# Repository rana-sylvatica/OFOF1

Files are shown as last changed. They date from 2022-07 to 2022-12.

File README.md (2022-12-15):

# OFOF1
Open-frame case design for the Open Frame1 board

## Overview

The goal of this project is to create a "bare miniumum" case design for the OF1 board, allowing aspiring makers to construct quality digital controllers as cheaply and simply as possible.

The controller is built as three layers (bottom panel, OF1 board, top panel) separated by standoffs leaving the sides open, hence the "open frame" in the title.  There are two versions of the OFOF1 case, as shown below.  The first one (labeled OFOF1 in the files) uses a top panel with circular cutouts for 3D printed MX switch button housings.  The second version (OFOF1_alt) uses a top panel with square cutouts that fit the MX switches directly.





## OF1 Board

Please refer to the Open Frame1 repository for information about the board

https://github.com/GregTurbo/Open-Frame1

## Panels

There are many ways to fabricate the top and bottom panels.  The method I am using is ordering them as aluminum PCBs from JLCPCB.  This is cheap, strong, and allows for logos or other designs to be built into the panel.  

However, JLCPCB has a minimum order quantity of 5, so this is not the most economical for a one-off build.

Another good method would be to order the panels through a laser-cutting service like SendCutSend (for those in the USA/Canada).  3mm acrylic or MDF or 1.6mm aluminum would both be suitable materials, and wouldn't be very expensive to get manufactured.  The panels can also be cut by hand from MDF or plywood or whatever.  Just know that you may need longer screws if you use a material thicker than 3mm.

Important note: assuming you have long enough screws, the bottom panel can be as thick as you'd like.  The top panel however should be 3mm or less in thickness to allow the screw-together button housings to fit properly.  For the OFOF1_alt, the top panel should be 1.5-1.6mm thick to allow the switches to clip into place.

The files for the bottom panel, top panel, and alternate top panel are provided in DXF format (2D CAD), STEP format (3D CAD), and as Gerber PCB fabrication files.  

Also included is a DXF file for a cover plate for the alt version.  This is optional but can be laser cut from clear acrylic to recess the switches somewhat and also allow for custom art, sandwiched between the top panel and cover plate.  If you go this route you will need longer screws than the ones listed below for the alt version

Outer dimensions of the panels are 14.5"x7".

## Standoffs

The standoffs that hold the layers at the proper spacing are designed to be 3D printed.  They can be printed at home or ordered using an online 3D printing service such as the one offered by JLCPCB.  If ordering from JLC, it is fine to use the cheapest option for resin (9000R), and make sure to use the versions of the files with x8 or x10 in the filename. 



A complete build requires 4 corner standoffs, 5 bottom standoffs, and 5 top standoffs.  Note that there are two different versions of the corner and top standoffs:
The ones labeled "tall" are for the regular OFOF1 build with an aluminum top panel. The ones labeled "short" are for the OFOF1_alt build. If using a 3mm top panel (acrylic, wood, etc.) the standoffs will need to be filed down approx. 1 mm to fit properly.

Files for these are provided in STL format, both as individual parts for at-home printing and panelized parts for ordering.  

If you do not like the open-frame look of the controller, there are 3D printable files for three configurations (regular, regular with acrylic/3mm thick top panel, and alt) that provide solid sidewalls.  These replace the standoffs described above.  



The STL files for at-home printing contain several parts, so open in your slicer program of choice to separate.  If arranged as shown it is possible to print all parts at the same time on an Ender3-sized print bed.



Also included are files for sidewalls that can be printed in one piece in resin by JLC.

Note: if using an aluminum bottom panel it may be preferable to cover the underside in non-conductive material (painter's tape, paint, full-sheet sticker paper, etc) to prevent accidental shorting across hotswap sockets on particularly agressive keystrokes that may bend the PCB.

## Buttons

The OF1 board and OFOF1 case work with any MX-style mechanical switch.  The OFOF1 uses the screw-together button housings shown below.



To assemble, the switch is placed into the bottom half of the housing, and the top half is screwed into the bottom half through the hole in the top panel.  The keycap is then pressed onto the switch stem.  As with the standoffs, these can be printed at home or ordered from JLC.  Please note that if you use a top panel thinner than 3mm, you will need an o-ring around the top housing, under the panel (see Hardware section).

A panelized file is available that includes parts for 3 complete buttons (top half, bottom half, and keycap).  The black resin or LEDO6060 resin from JLC are the recommended materials for these parts. For a full set, 7 copies of the file need to be ordered.  The files of the individual parts are also available


Note: these housings are compatible with official Frame1 keycaps or any circular keycap that is 20.64mm or less in diameter.

For more information on 3D printing keycaps, check out: https://github.com/rana-sylvatica/circle-keycaps

The OFOF1_alt does not use these button housings, so any keycaps will work for that. Circular, square, etc are all fine.

## Hardware

Here's what is needed to assemble a full controller:

### OFOF1

x9 16mm Flanged Button Head Screw
https://www.mcmaster.com/90909A724/

x9 Narrow Base Weld Nut
https://www.mcmaster.com/90594A320/

x20 O-ring (not needed if using a 3mm thick acrylic/MDF top panel)
https://www.mcmaster.com/9452K75/

### OFOF1-alt

x9 10mm Flanged Button Head Screw
https://www.mcmaster.com/90909A722/

x9 Narrow Base Weld Nut
https://www.mcmaster.com/90594A320/

## Additional info

If you wan to know more or discuss these designs, DM on discord at bjartskular1#6913 or join my server at https://discord.gg/9wBaMWgJkv

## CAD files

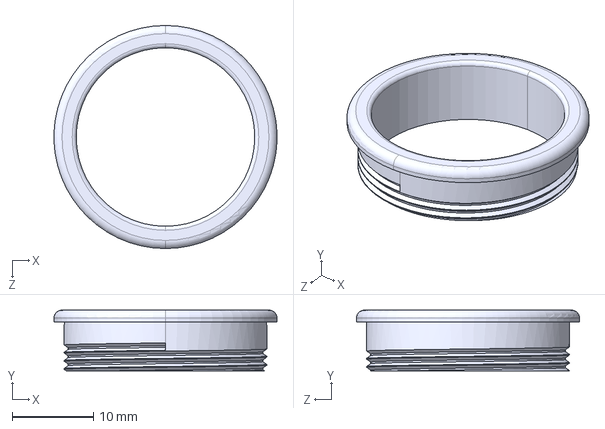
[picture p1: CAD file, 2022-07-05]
Buttons/Housing_top.STEP
27.5 x 7.50 x 27.5 mm

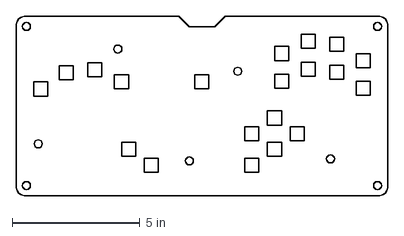
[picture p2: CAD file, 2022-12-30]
Panels/DXF/ofof1_top_alt_usb_cutout.DXF
14.5 x 7.00 in

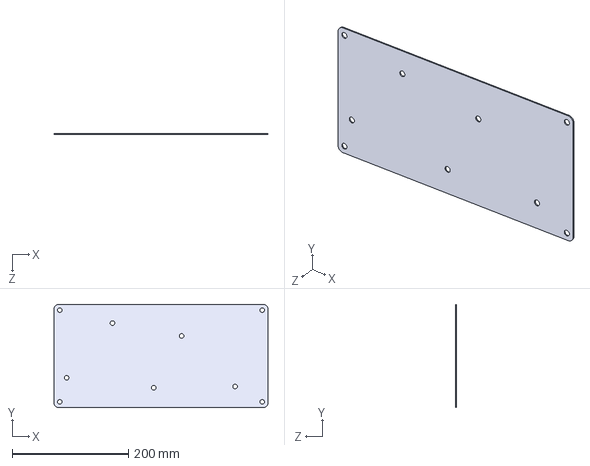
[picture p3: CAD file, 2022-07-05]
Panels/STEP/ofof1_bottom.STEP
368.3 x 177.8 x 1.60 mm

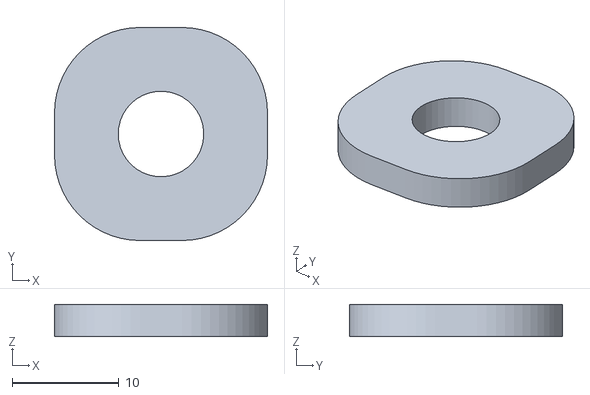
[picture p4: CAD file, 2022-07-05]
Standoffs/Bottom_standoff.STL
19.9 x 19.9 x 3.00

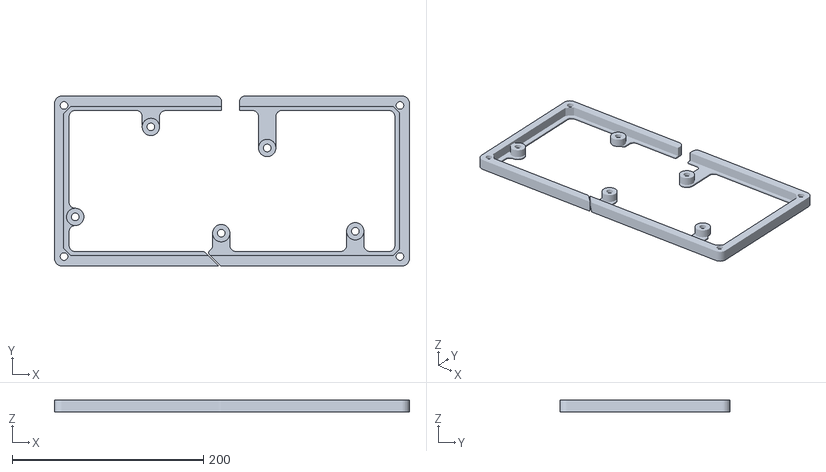
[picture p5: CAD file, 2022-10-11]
Standoffs/Sidewalls/ofof1-walls-3dprint-acrylic.STL
370.8 x 177.8 x 13.0

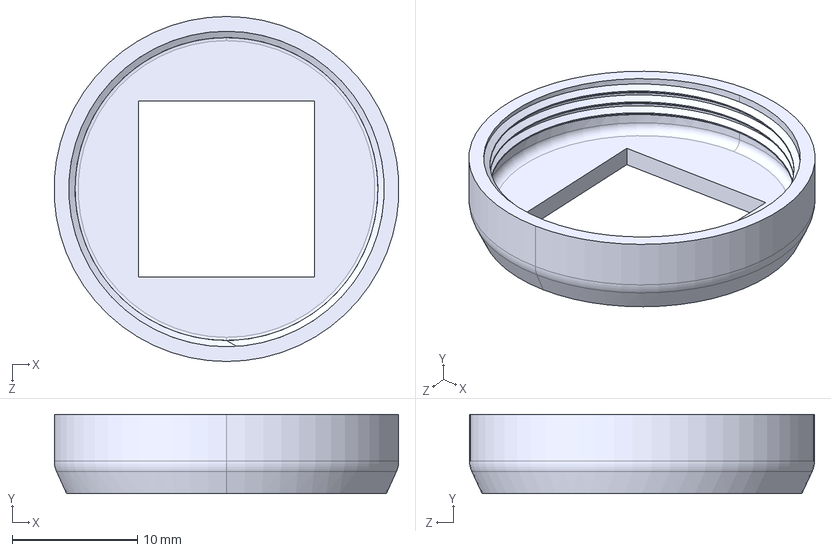
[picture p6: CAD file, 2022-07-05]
Buttons/Housing_bottom.STEP
27.5 x 6.30 x 27.5 mm

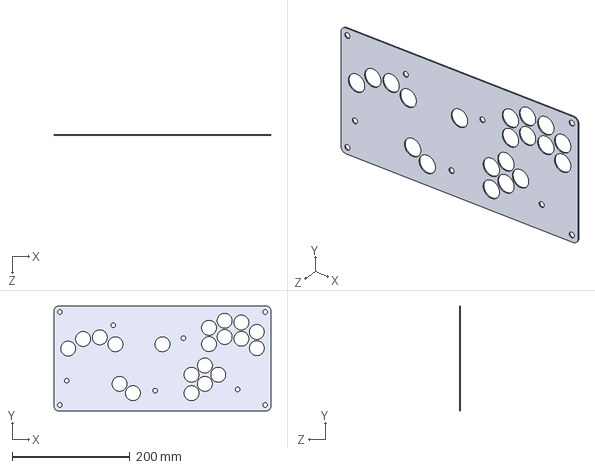
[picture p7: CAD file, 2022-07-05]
Panels/STEP/ofof1_top.STEP
368.3 x 177.8 x 1.60 mm

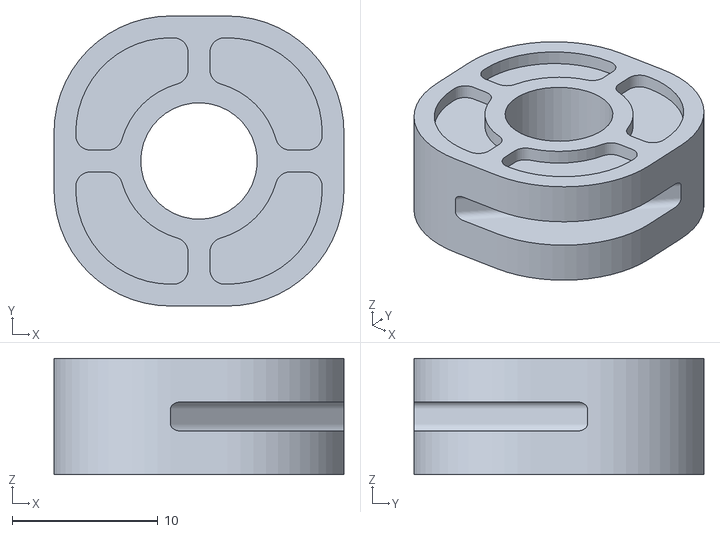
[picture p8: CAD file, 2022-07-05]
Standoffs/Corner_standoff_short.STL
19.9 x 19.9 x 8.00

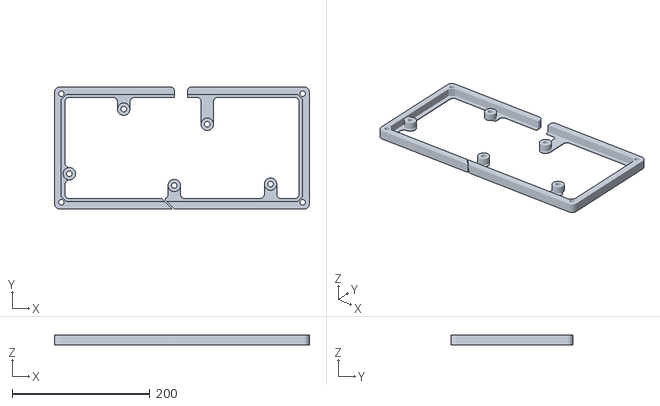
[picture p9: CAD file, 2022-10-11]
Standoffs/Sidewalls/ofof1-walls-3dprint.STL
370.8 x 177.8 x 14.0

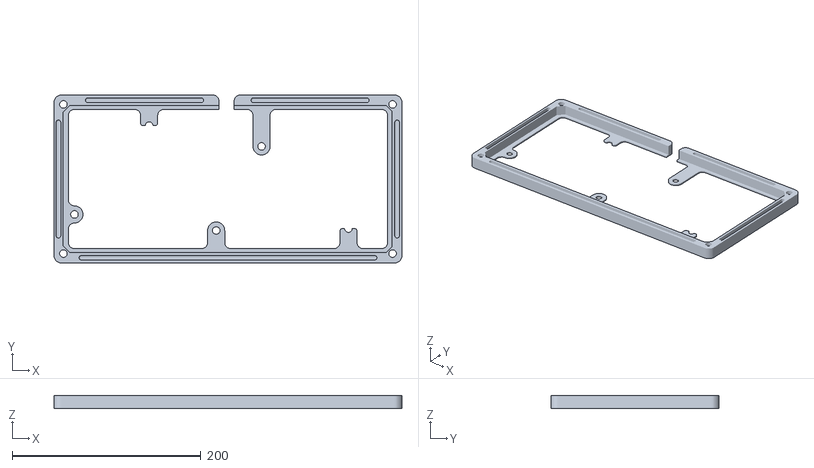
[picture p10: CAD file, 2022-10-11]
Standoffs/Sidewalls/ofof1-walls-JLC.STL
368.3 x 177.8 x 14.0

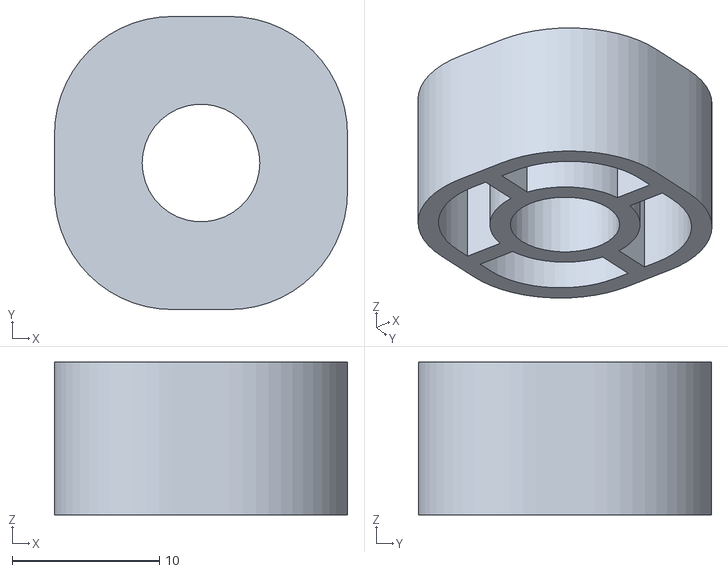
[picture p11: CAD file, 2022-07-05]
Standoffs/Top_standoff_tall.STL
19.9 x 19.9 x 10.4

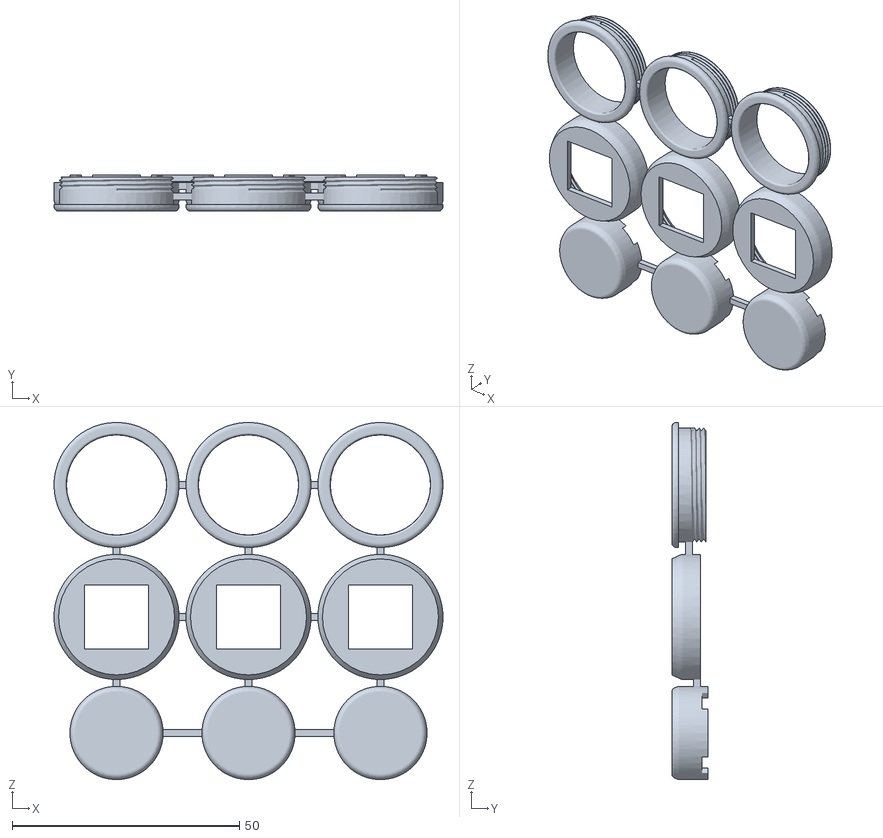
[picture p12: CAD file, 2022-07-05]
Buttons/Keycap_Housing_inch_x3.STL
85.5 x 8.00 x 78.5

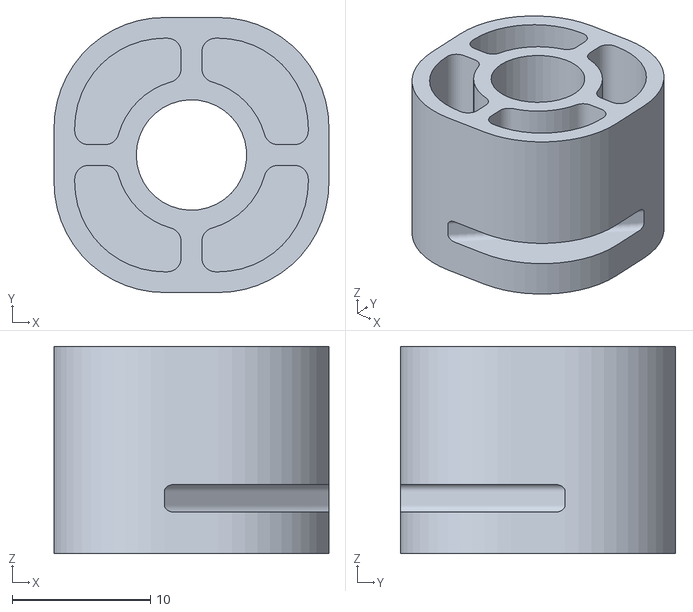
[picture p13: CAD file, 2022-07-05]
Standoffs/Corner_standoff_tall.STL
19.9 x 19.9 x 15.0

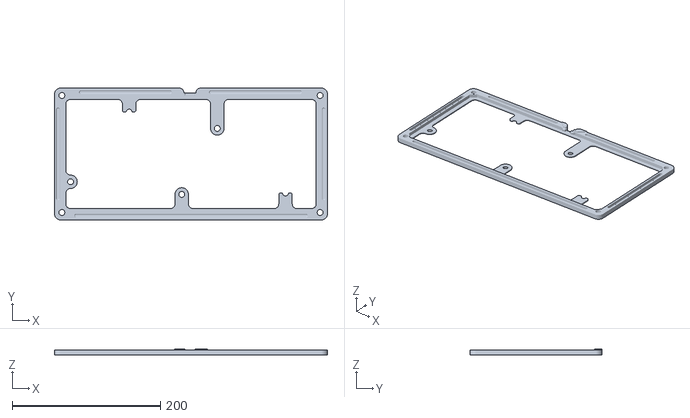
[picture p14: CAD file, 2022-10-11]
Standoffs/Sidewalls/ofof1-walls-JLC-alt.STL
368.3 x 177.8 x 8.60

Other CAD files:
Buttons/Keycap.STEP
Panels/STEP/ofof1_top_alt.STEP
Standoffs/Sidewalls/ofof1-walls-3dprint-alt.STL
Standoffs/Top_standoff_short.STL
Buttons/Housing_bottom.STL
Buttons/Housing_top.STL
Buttons/Keycap.STL
Panels/DXF/ofof1_bottom.DXF
Panels/DXF/ofof1_top.DXF
Standoffs/Bottom_standoff_x10.STL
Standoffs/Corner_standoff_short_x8.STL
Standoffs/Corner_standoff_tall_x8.STL
Standoffs/Sidewalls/ofof1-walls-JLC_acrylic.STL
Standoffs/Top_standoff_short_x10.STL
Standoffs/Top_standoff_tall_x10.STL

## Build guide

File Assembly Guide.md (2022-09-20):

# How to assemble an OFOF1 (regular version)

These are the instructions for building your very own OFOF1 controller.  If you can assemble a LEGO set and can do a bit of basic soldering, this will be very doable.  It should take about 2 hours for a first time builder to go from kit to finished controller.

## Step 1: Tools

Here is the bare minimum of what you will need:
 - Soldering iron
 - Solder
 - Flush cutters (flat nail clippers can also work)
 - Hobby knife
 - 3mm hex key

A multimeter is not technically required but will make your life easier.  Flux can make the soldering easier but isn't necessary (I don't use it).



---

## Step 2: Parts

Here are all the parts that you will need (the packing list shows what I pack in the DIY kits I sell and includes a few spares of button parts, hotswap sockets, hardware, etc.)



packing list

---

## Step 3: Buttons

Break the button panels apart and sort the top housings, bottom housings, and keycaps


Use the flush cutters and/or the hobby knife to clip/cut the remaining connecting bits from the button parts

Insert a top housing through the hole in the top panel


Put an o-ring over the protruding portion of the top housing


Screw the bottom housing onto the threads of the top housing until it is snug (not overly tight) and the square hole is parallel with the top panel



Repeat for the remaining 19 buttons.  When finished it should look like this:



Insert switches into all the housings as shown - make sure the pins are aligned towards the bottom of the panel to fit with the hotswap sockets on the OF1 PCB

Do not put keycaps on yet



---

## Step 4: Soldering the pico

There are two methods of soldering the pico onto the OF1 PCB.  **The first method is for experienced solderers only.** If you do not feel very comfortable soldering or do not have a mulitmeter, I recommend the second method.

Before starting either method, it is a good idea to program the pico and make sure it works.  Plug it in to your computer with a micro USB cable and follow the instructions at https://github.com/JulienBernard3383279/pico-rectangle/ or https://github.com/JonnyHaystack/HayBox.  If the pico does not show up on the computer when initially plugged in, it is defective and you should get a new pico.

### Method 1:

Put a small amount of solder onto the USB data pads under the pico



Attach the pico to the OF1 board with tape or by soldering one of the debug pins to tack it in place. Turn the board over and solder the data pads through the plated holes as shown, while pressing down on the board.  The solder on the pads on the pico should flow into the plated holes but you may need to add a little bit of additional solder to get enough heat flow.


After doing this and before soldering the rest of the pins, check continuity with a multimeter between the pins on the pico USB (circled on the left) and the d+ and d- pins on the OF1 board (circled on the right).  Also make sure the data pins do not have continuity to each other. 



Use this image as reference for finding d+ and d- on the pico USB



Finally, solder the rest of the pins.  Finished result should look something like this:



### Method 2:

Instead of surface mounting the pico to the OF1 board, you can buy a Micro USB to USB C cable and pin headers, which greatly reduces the chances for soldering issues that are difficult to fix.  Below are links to examples that will work well for this (not provided in the DIY kit but recommended to purchase if you are a novice solderer)

https://www.amazon.com/dp/B0744BKDRD

https://www.amazon.com/MCIGICM-Header-2-45mm-Arduino-Connector/dp/B07PKKY8BX

Doing it this way will look like this. Just solder the pin headers into the OF1 PCB and then solder the pico onto the headers, and plug the cable into the pico and the secondary USB C port on the OF1 PCB. 


 
---
 
## Step 5: Soldering the hotswaps and assembling the case

After soldering the pico, return to the top panel with button housings and switches.  Placing it face-up, insert the 16mm M5 screws into the 5 inner holes in the panel, ignoring the corners for now.  Place small bits of painter's tape over the switches to keep them in place.



Take the top standoffs and break them apart and clean off the connecting bits



Turn the top panel over and place the standoffs as shown onto the 5 screws



Place the OF1 PCB onto the switches/standoffs as shown.  Ensure that the pins of the switches are not bent.



Place the hotswap sockets on the switch pins and push them into place.  You may need to lift up the top panel and squeeze between the switch and the hotswap socket to make sure they are both properly seated.  The socket should rest flush against the OF1 PCB.



Solder the hotswap sockets to the board. Done properly the should look like this:


Take the bottom standoffs and break them apart and clean off the connecting bits, then place them on the OF1 PCB, over the 5 screws as shown.





Place the bottom panel on top of the bottom standoffs and gently screw on M5 weld nuts onto the screws in the 5 inner holes as shown.  They do not need to be tight, just enough to hold the whole thing together.



Break apart and clean the corner standoffs, and then place them in each corner.  Place a weld nut through each corner hole and cover with a bit of painter's tape to hold in place.




Turn the controller over, remove the painter's tape from the screws on the top panel, place screws in the four corners, and tighen all screws with the 3mm hex key.

Ensure everything is lined up correctly before tightening.



Turn the controller over and remove the painter's tape from the corner weld nuts.  Take the anti-slip foam pad and peel it off the paper backing.



Stick on the bottom panel as shown.  The adhesive is fairly strong so be careful to line it up correctly.


Turn the controller back over, and place the keycaps on the switches.



Congratulations! You finished your OFOF1!

If you want a carrying case, this one works well:

https://www.amazon.com/dp/B092LX8865



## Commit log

2022-07-06 Update README.md
    Fixed typos in panel dimensions and link to 10mm screws
2022-09-19 Create Assembly Guide.md
2022-09-19 Update Assembly Guide.md
